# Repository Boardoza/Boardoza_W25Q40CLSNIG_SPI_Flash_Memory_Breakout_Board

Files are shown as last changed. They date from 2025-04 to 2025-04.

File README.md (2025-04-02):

# Boardoza W25Q40CLSNIG Serial Flash Memory Breakout Board

The **Boardoza W25Q40CLSNIG** is a compact and high-performance **SPI Flash memory breakout board** built around the Winbond W25Q40CLSNIG chip. Offering **4 megabits (512 kilobytes)** of non-volatile storage, it is ideal for embedded applications requiring **code execution, configuration retention, or data logging**.

With support for **SPI communication up to 104 MHz**, this module enables fast and reliable read/write operations, even in timing-critical environments. The board is equipped with power and I/O indicators and is fully compatible with microcontrollers and single-board computers that require external SPI-based flash memory.

## [Click here to purchase!](https://www.ozdisan.com/maker-ve-iot-urunleri/boardoza/boardoza-modulleri/BOARDOZA-W25Q/1206520)

|Front Side|Back Side|
|:---:|:---:|
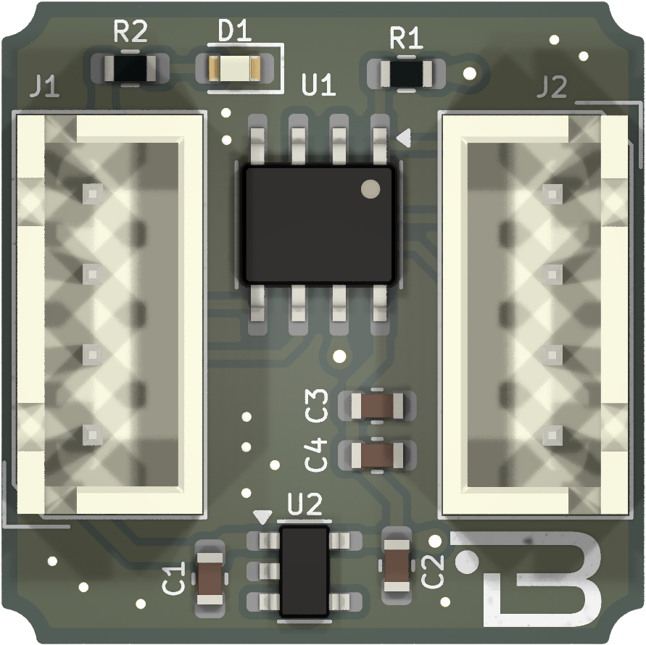
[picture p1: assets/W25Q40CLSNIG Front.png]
Front
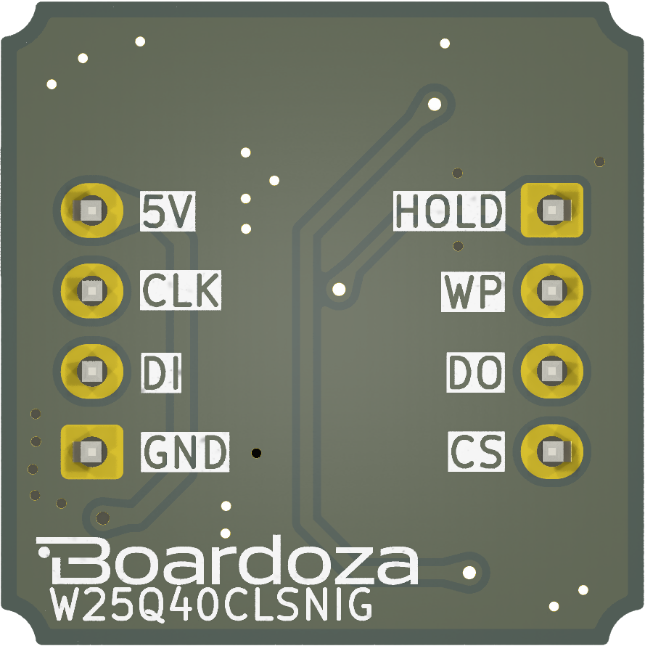
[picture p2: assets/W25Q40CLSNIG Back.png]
Back
| | |

---

## Key Features

- **4M-bit / 512KB Serial Flash Memory:** Ideal for code or data storage in embedded systems.
- **Fast SPI Interface:** Operates at up to 104 MHz clock speed.
- **Flexible Erase Architecture:** Supports uniform 4KB sectors, and larger 32KB / 64KB block erase operations.
- **Durable & Reliable:** Over 100,000 write/erase cycles with >20 years of data retention.
- **Low Power Consumption:** Optimized for battery-powered systems.
- **Power LED Indicator (D1):** Helps monitor power state visually.

---

## Technical Specifications

**Model:** Winbond W25Q40CLSNIG  
**Input Voltage:** 3.3V – 5V  
**Functions:** Serial Flash Memory  
**Memory Size:** 4 Mbit (512KB)  
**Speed:** Up to 104 MHz  
**Interface:** SPI  
**Endurance:** 100,000+ write/erase cycles  
**Data Retention:** > 20 years  
**Operating Temperature:** -40°C ~ +85°C  
**Board Dimensions:** 20mm x 20mm  

---

## Board Pinout

### ( J1 ) Power and Basic SPI Interface

| Pin Number | Pin Name | Description |
|:---:|:---:|---|
| 1 | 5V | Positive Power Supply |
| 2 | CLK  | Serial Clock Input (SCK) |
| 3 | DI | Data Input (IO0 / MOSI) |
| 4 | GND  | Ground |

### ( J2 ) Additional SPI Control Pins

| Pin Number | Pin Name | Description |
|:---:|:---:|---|
| 1 | CS | Chip Select (Active Low) |
| 2 | DO | Data Output (IO1 / MISO) |
| 3 | WP | Write Protect Input (IO2) |
| 4 | HOLD  | Hold Input (IO3) |

---

## Board Dimensions

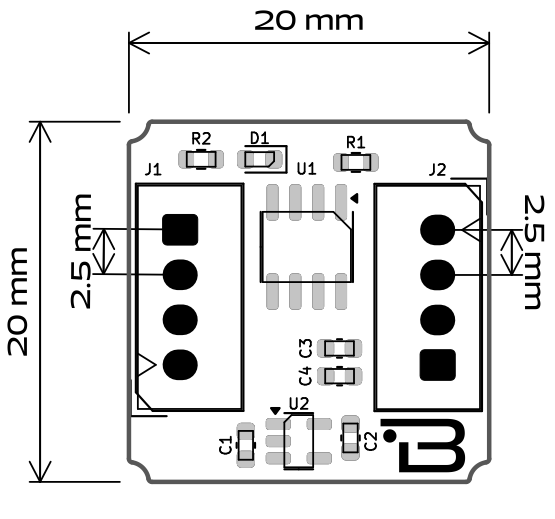
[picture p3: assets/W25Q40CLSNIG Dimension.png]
Board Dimensions


---

## Step Files

[Boardoza W25Q40CLSNIG.step](./assets/W25Q40CLSNIG%20Step.step)

---

## Datasheet

[W25Q40CLSNIG Datasheet.pdf](./assets/W25Q40CLSNIG%20Datasheet.pdf)

---

## Version History

- V1.0.0 – Initial Release

---

## Support

For questions or technical support, please contact **<support@boardoza.com>**

---

## License

Shield: [][cc-by-sa]  

This work is licensed under a [Creative Commons Attribution-ShareAlike 4.0 International License][cc-by-sa].  

[][cc-by-sa]  

[cc-by-sa]: http://creativecommons.org/licenses/by-sa/4.0/  
[cc-by-sa-image]: https://licensebuttons.net/l/by-sa/4.0/88x31.png  
[cc-by-sa-shield]: https://img.shields.io/badge/License-CC%20BY--SA%204.0-lightgrey.svg

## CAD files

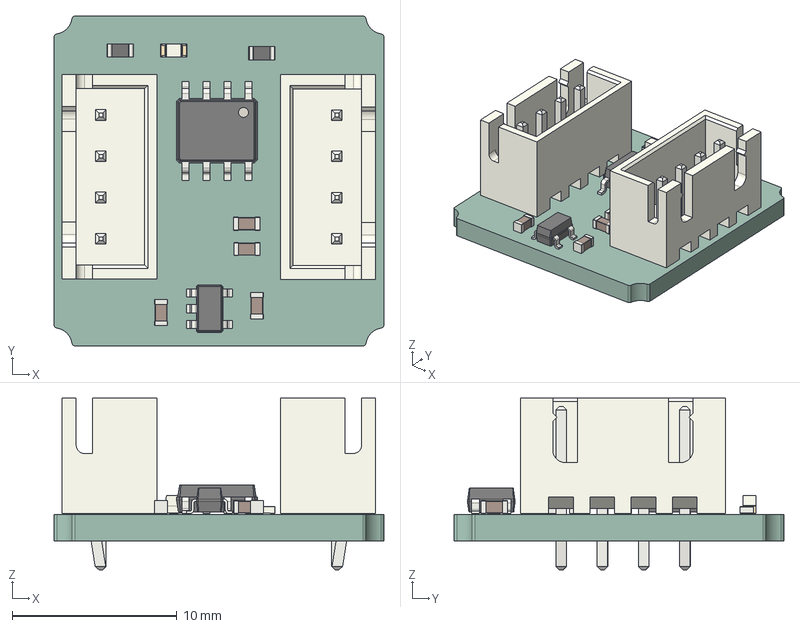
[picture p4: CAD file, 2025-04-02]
assets/W25Q40CLSNIG Step.step
20.0 x 20.0 x 10.4 mm
R_0603_1608Metric x 2
JST_B4B_XH_A x 2
SOIC_8_39x49mm_P127mm
LED_0603_1608Metric
C_0603_1608Metric x 4
SOT_23_5
_autosave-B-W25Q40CLSNIG-BRK-01MBR-R01_PCB

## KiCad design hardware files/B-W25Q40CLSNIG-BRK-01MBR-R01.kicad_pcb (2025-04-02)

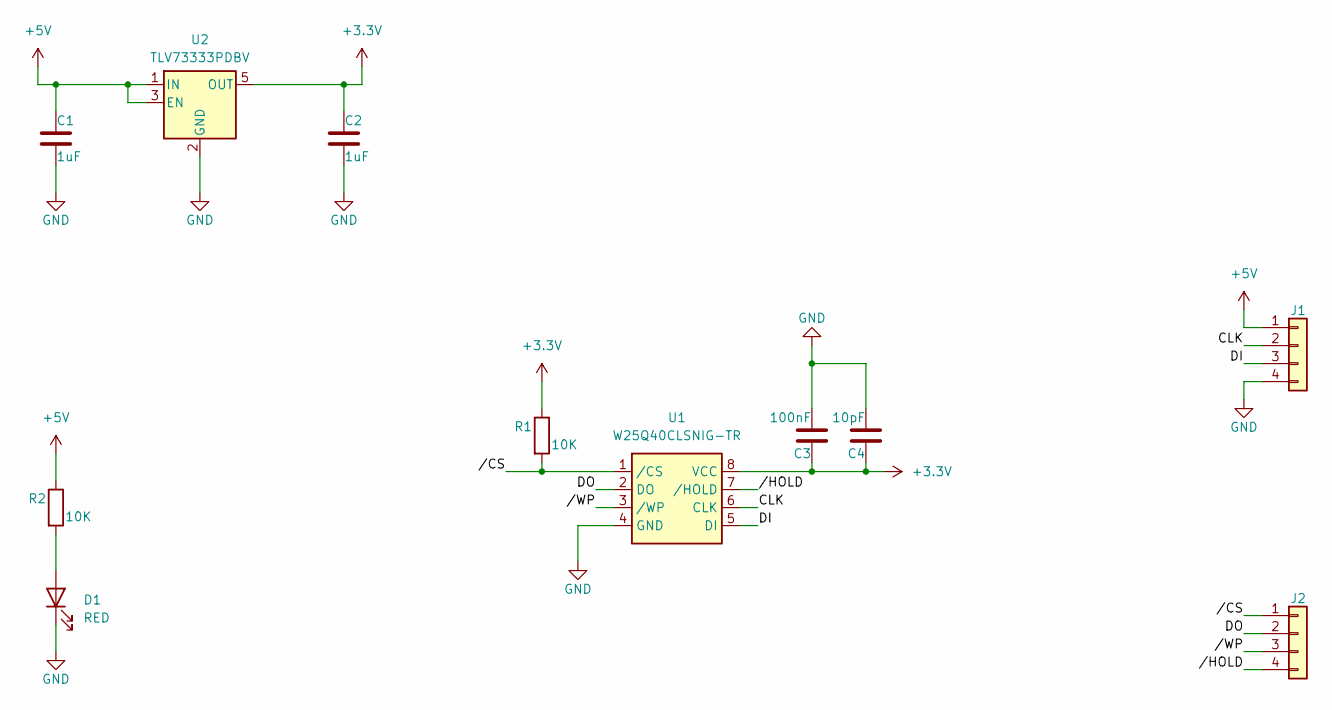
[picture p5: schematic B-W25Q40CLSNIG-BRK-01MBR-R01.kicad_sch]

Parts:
C1, C2: 1uF; C_0603_1608Metric
C3: 100nF; C_0603_1608Metric
C4: 10pF; C_0603_1608Metric
D1: RED; LED_0603_1608Metric
J1, J2: Conn_01x04; 2317-04S_1x04_P2.50mm_Vertical
R1, R2: 10K; R_0603_1608Metric
U1: W25Q40CLSNIG-TR; SOIC-8_3.9x4.9mm_P1.27mm
U2: TLV73333PDBV; SOT-23-5

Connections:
+3.3V: C2.1, C3.1, C4.1, R1.1, U1.8 (VCC), U2.5 (OUT)
+5V: C1.1, J1.1, R2.1, U2.1 (IN), U2.3 (EN)
/CLK: J1.2, U1.6 (CLK)
/DI: J1.3, U1.5 (DI)
/DO: J2.2, U1.2 (DO)
//CS: J2.1, R1.2, U1.1 (/CS)
//HOLD: J2.4, U1.7 (/HOLD)
//WP: J2.3, U1.3 (/WP)
GND: C1.2, C2.2, C3.2, C4.2, D1.1 (K), J1.4, U1.4 (GND), U2.2 (GND)
unnamed: D1.2 (A), R2.2

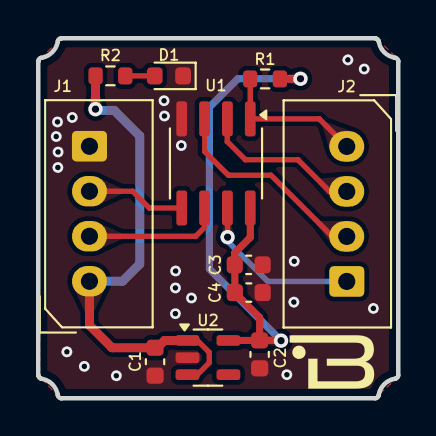
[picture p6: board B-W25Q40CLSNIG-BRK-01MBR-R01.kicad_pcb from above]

Board: 2 copper layers, 20.0 x 20.0 mm, 11 parts (0 on the bottom side), 10 nets.

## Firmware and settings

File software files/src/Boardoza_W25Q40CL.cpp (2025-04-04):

#include "Boardoza_W25Q40CL.h"

Boardoza_W25Q40CL::Boardoza_W25Q40CL(){}

/**
 * @brief Initializes the W25Q40CL Flash Memory on the Boardoza platform.
 * 
 * This function configures the necessary settings and parameters for using the W25Q40CL Flash Memory.
 * 
 * @param csPin The chip select pin connected to the Flash Memory.
 */
void Boardoza_W25Q40CL::begin(uint8_t csPin) {
    pinMode(csPin, OUTPUT);
    digitalWrite(csPin, HIGH);
    _csPin = csPin;
    SPI.begin();
    SPI.setBitOrder(MSBFIRST);
    SPI.setDataMode(SPI_MODE3);
    deactivatePD();
    disableWrite();
}

/**
 * @brief Deactivates the power down mode of the W25Q40CL Flash Memory on the Boardoza platform.
 * 
 * This function deactivates the power down mode of the Flash Memory by sending the appropriate command and waiting for completion.
 */
void Boardoza_W25Q40CL::deactivatePD() {
    digitalWrite(_csPin, LOW);
    SPI.transfer(RELEASE_POWER_DOWN);
    digitalWrite(_csPin, HIGH);
    waitForCompletion();
}

/**
 * @brief Waits for the completion of a command on the W25Q40CL Flash Memory on the Boardoza platform.
 * 
 * This function checks the status register of the Flash Memory to wait for the completion of a command.
 */
void Boardoza_W25Q40CL::waitForCompletion() {
    digitalWrite(_csPin, LOW);
    SPI.transfer(READ_STAT_REG1);
    while (bitRead(SPI.transfer(0),0) & 1) {
    }
    digitalWrite(_csPin, HIGH);
}

/**
 * @brief Enables write operations on the W25Q40CL Flash Memory on the Boardoza platform.
 * 
 * This function enables write operations on the Flash Memory by sending the write enable command and waiting for completion.
 */
void Boardoza_W25Q40CL::enableWrite() {
    digitalWrite(_csPin, LOW);
    SPI.transfer(WRITE_ENABLE);
    digitalWrite(_csPin, HIGH);
    waitForCompletion();
}

/**
 * @brief Disables write operations on the W25Q40CL Flash Memory on the Boardoza platform.
 * 
 * This function disables write operations on the Flash Memory by sending the write disable command and waiting for completion.
 */
void Boardoza_W25Q40CL::disableWrite() {
    digitalWrite(_csPin, LOW);
    SPI.transfer(WRITE_DISABLE);
    digitalWrite(_csPin, HIGH);
    waitForCompletion();
}

/**
 * @brief Performs a chip erase operation on the W25Q40CL Flash Memory on the Boardoza platform.
 * 
 * This function initiates a chip erase operation on the Flash Memory by enabling write operations 
 * sending the chip erase command, waiting for completion, and then disabling write operations.
 */
void Boardoza_W25Q40CL::chipErase() {
    enableWrite();
    digitalWrite(_csPin, LOW);
    SPI.transfer(CHIP_ERASE);
    digitalWrite(_csPin, HIGH);
    waitForCompletion();
    disableWrite();
}

/**
 * @brief Retrieves the manufacturer ID of the W25Q40CL Flash Memory on the Boardoza platform.
 * 
 * This function retrieves the manufacturer ID of the Flash Memory by sending the appropriate command and reading the response.
 * 
 * @return The manufacturer ID of the Flash Memory.
 */
byte Boardoza_W25Q40CL::manufecturerID() {
    digitalWrite(_csPin, LOW);
    SPI.transfer(MANUFECTURER_ID);
    SPI.transfer(0);
    SPI.transfer(0);
    SPI.transfer(0);
    byte value = SPI.transfer(0);
    digitalWrite(_csPin, HIGH);
    waitForCompletion();
    return value;
}

/**
 * @brief Retrieves the JEDEC ID of the W25Q40CL Flash Memory on the Boardoza platform.
 * 
 * This function retrieves the JEDEC ID of the Flash Memory by sending the appropriate command and reading the response.
 * 
 * @return The JEDEC ID of the Flash Memory.
 */
byte Boardoza_W25Q40CL::jedecID() {
    digitalWrite(_csPin, LOW);
    SPI.transfer(JEDEC_ID);
    SPI.transfer(0);
    byte value = SPI.transfer(0);
    digitalWrite(_csPin, HIGH);
    waitForCompletion();
    return value;
}

/**
 * @brief Enters low power mode on the W25Q40CL Flash Memory on the Boardoza platform.
 * 
 * This function puts the Flash Memory into low power mode by sending the appropriate command and waiting for completion.
 */
void Boardoza_W25Q40CL::lowPower() {
    digitalWrite(_csPin, LOW);
    SPI.transfer(POWER_DOWN);
    digitalWrite(_csPin, HIGH);
    waitForCompletion();
}

/**
 * @brief Checks if the current page address has reached the end and updates the page number and address if necessary.
 * 
 * This function checks if the current page address has reached the end of a page and updates the page number and address accordingly.
 * If the current page address is greater than 255, the page number is incremented and if the page number exceeds the maximum value, it is reset to 0.
 */
void Boardoza_W25Q40CL::pageEnd() {
    if(_pageAddress > 255) {
        _pageNumber++;
        if(_pageNumber > W25Q40) {
         _pageNumber = 0;
        }
        _pageAddress = 0;
    }
}
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

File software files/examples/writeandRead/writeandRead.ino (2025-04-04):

#include "Boardoza_W25Q40CL.h"

#define WP 25
#define HOLD 33

Boardoza_W25Q40CL flash;
uint8_t buffer_tx[128];
uint8_t buffer_rx[128];

void setup() {
  Serial.begin(115200);
  while(!Serial) {

  }
  pinMode(WP, OUTPUT);
  pinMode(HOLD, OUTPUT);
  digitalWrite(WP, HIGH);
  digitalWrite(HOLD, HIGH);
  flash.begin(5);
  flash.chipErase();
  flash.lowPower();
}

uint8_t i;

void loop() {
  uint32_t pageAddress = 0; uint32_t pageNumber = 1;
  flash.deactivatePD();
  i = 0;
  buffer_tx[0]=1;
  buffer_tx[1]=2;
  buffer_tx[2]=3;
  buffer_tx[3]=4;
  buffer_tx[4]=5;
  buffer_tx[5]=6;
  buffer_tx[6]=7;
  buffer_tx[7]=8;
  buffer_tx[8]=9;
  while(i < 1) {
    flash.pageWriteData(pageNumber, pageAddress, buffer_tx, 9);
    //flash.writeData(pageNumber, pageAddress, 55);
    flash.pageEnd();
    i++;
    delay(5);
  }
  delay(100);
  pageAddress = 0; pageNumber = 1;
  i = 0;
  flash.pageReadData(pageNumber, pageAddress, buffer_rx,9);

  /*while (i<9)
    {
    Serial.println(buffer_rx[i]);
    i++;
    }*/

   while(i < 9) {
    Serial.println(flash.readData(pageNumber, pageAddress));
    pageAddress++;
    flash.pageEnd();
    i++;
    delay(5);
  }
  pageAddress = 0; pageNumber = 1;
  delay(500);
}
